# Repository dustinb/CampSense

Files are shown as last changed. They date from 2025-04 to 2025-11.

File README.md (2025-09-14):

# Camp Sense

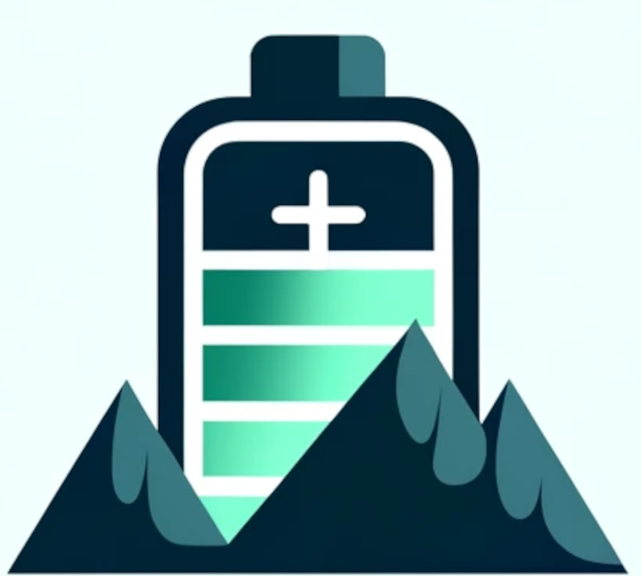
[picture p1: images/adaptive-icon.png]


**Battery energy monitoring and weather app with ESP32 hardware**

The Camp Sense app connects to the WattIsIt ESP32 hardware module via Bluetooth and displays battery energy usage and weather data.

## 🚀 Quick Start

- **📱 [Download App](https://apps.apple.com/us/app/camp-sense/id6741625671)** - Available on the App Store
- **🌐 [View Website](https://campsense.app)** - Full documentation and hardware details

## 📁 Repository Structure

- `App/` - React Native mobile app (Expo)
- `Arduino/` - ESP32 firmware sketch
- `v1.kicad_pro` - KiCad project

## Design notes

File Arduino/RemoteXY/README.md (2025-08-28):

## Remote XY

Before the Camp Sense app Remote XY was used for development. The sketch is in `Arduino/RemoteXY`.

The Remote XY is a free app is used to view data with bluetooh. This also has a setting for the shunt 50, 75, or 100 mV. The setting is persisted in eeprom (flash memory)

https://remotexy.com/en/editor/391325040dffc13fc4e74f019a2b24ee/

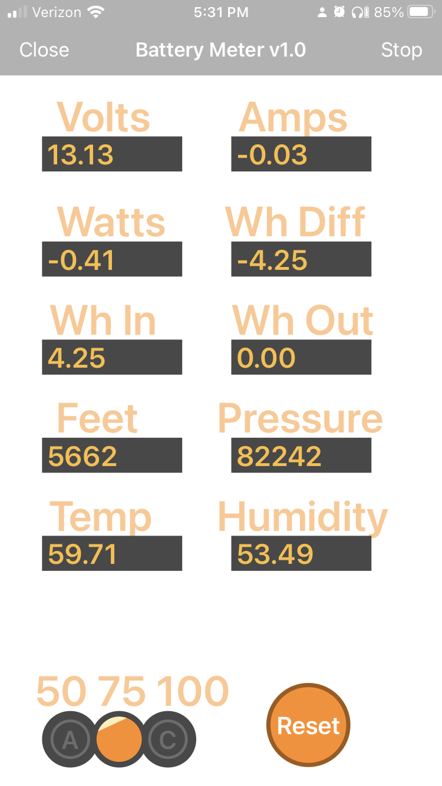
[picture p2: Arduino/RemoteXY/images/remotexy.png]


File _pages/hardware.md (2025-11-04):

---
layout: default
title: "Hardware - WattIsIt"
permalink: /hardware/
---

## WattIsIt Hardware

A battery watt meter using ADS1115 and a shunt to measure power usage. The Arduino sketch is located in `Arduino/WattIsIt`. Been using the DOIT ESP32 DEVKIT V1 board.

## Version 1.2

| KiCad Model | PCB |
| :---: | :---: |
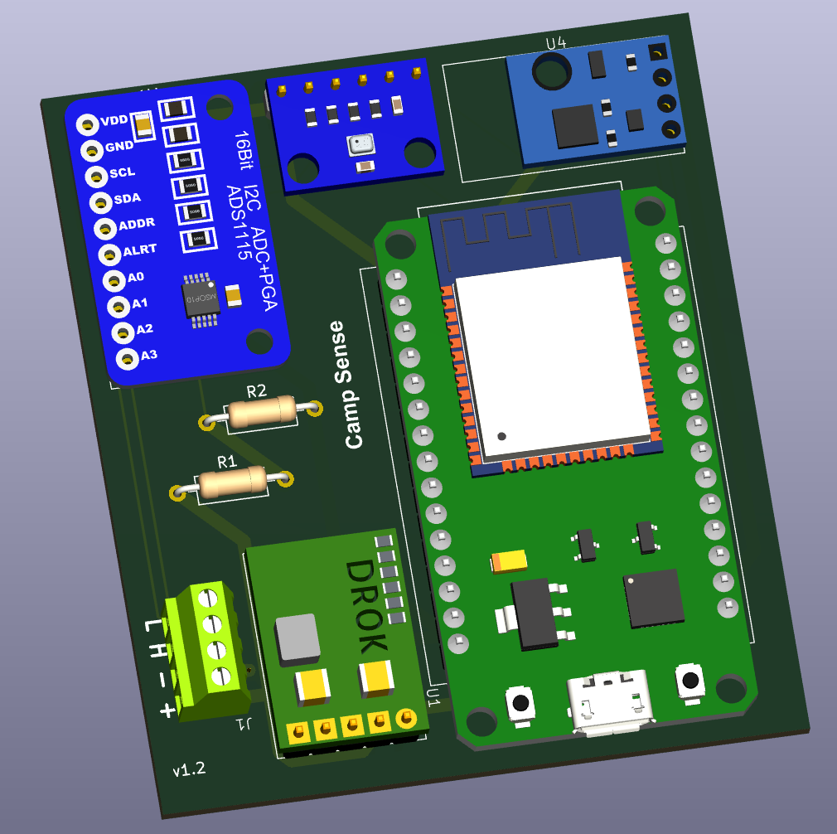
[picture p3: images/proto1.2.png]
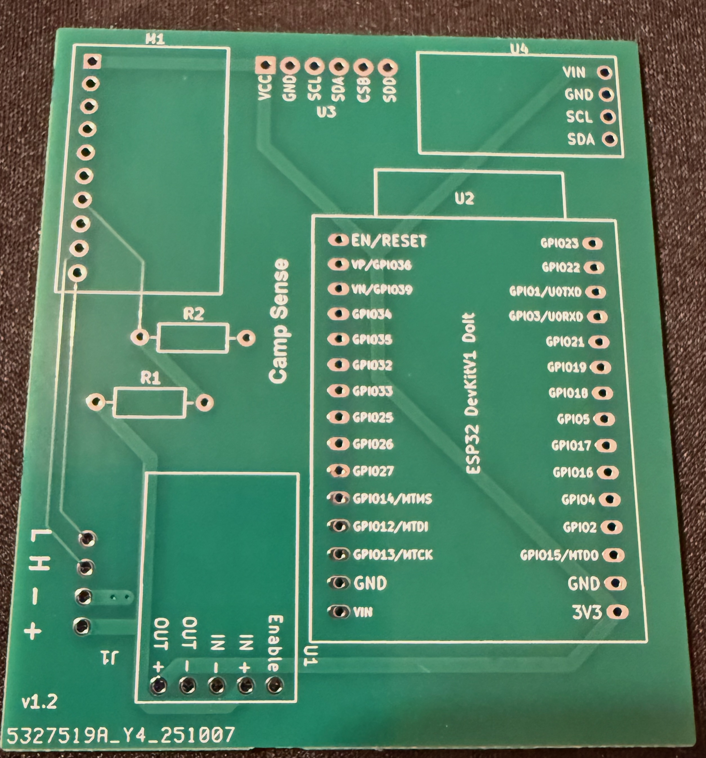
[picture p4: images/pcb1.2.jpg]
|  |  |

## Case & Battery Holder

Download all STLs for printing the hoder and case <a href="../images/camp_sense_stl.zip" >here</a>

| Hex | Oval |
| :---: | :---: |
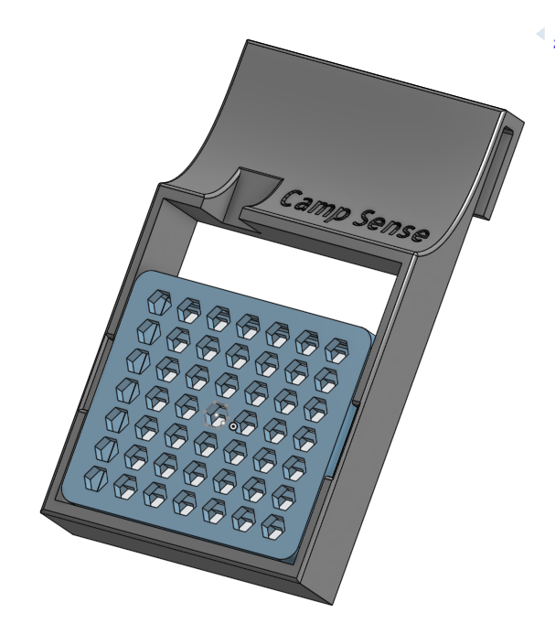
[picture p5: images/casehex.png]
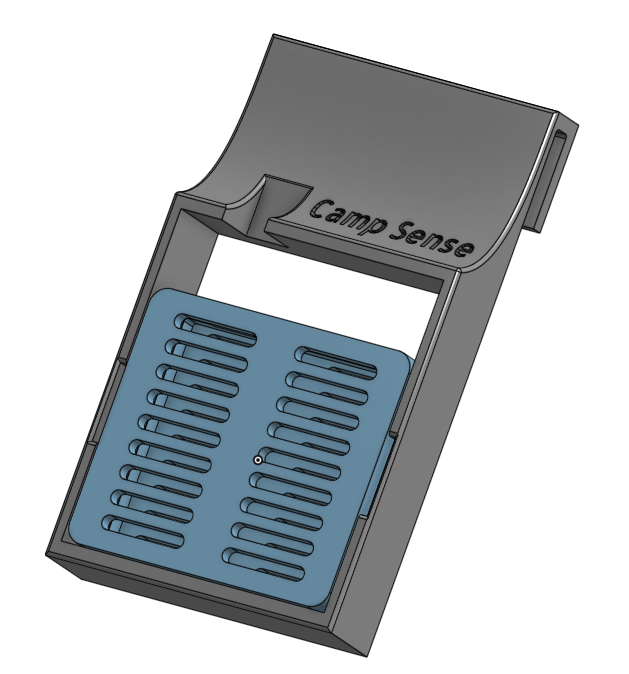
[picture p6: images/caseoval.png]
|   |  |

## Wiring Diagram

**+** Positive battery terminal

**-** Negative battery terminal

**L** Low side of current shunt resistor

**H** High side of current shunt resistor

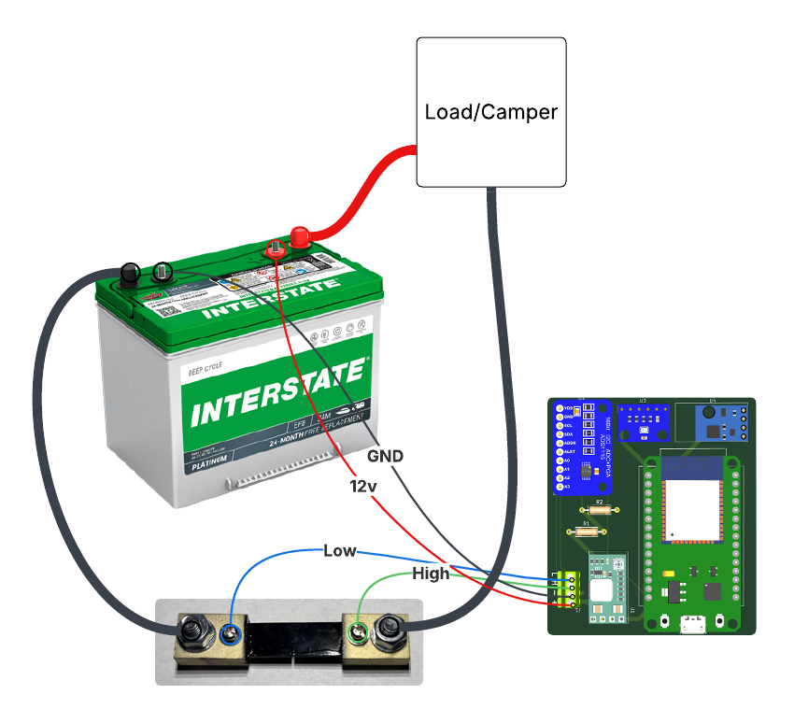
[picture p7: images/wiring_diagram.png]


## Bill of Materials

If using a BME280 on U3 can skip the AHT21 at U4.  The BME280 has tempurature, humidity and pressure/altitude.

| Item | Link |
| --- | --- |
| U2 ESP32 | [https://a.co/d/ff7WulK](https://a.co/d/ff7WulK) |
| M1 ADS1115 | [https://a.co/d/gfCO6jt](https://a.co/d/gfCO6jt) |
| U1 Voltage Reg | [https://a.co/d/2Gd8mMj](https://a.co/d/2Gd8mMj) |
| U4 AHT21 | [https://a.co/d/6xBWBLx](https://a.co/d/6xBWBLx) |
| U3 BMP280 | [https://a.co/d/1HV9oyw](https://a.co/d/1HV9oyw) |
| U3 BME280 | [https://a.co/d/eRQ7Lw4](https://a.co/d/eRQ7Lw4) |
| J1 Terminals | [https://a.co/d/8nVocXb](https://a.co/d/8nVocXb) |
| J1 JST Connector | [https://a.co/d/0xq4sMO](https://a.co/d/0xq4sMO) |
| Shunt | [https://a.co/d/2KoI4U9](https://a.co/d/2KoI4U9) |
| R1 36k Ohm | [https://a.co/d/88x0EcR](https://a.co/d/88x0EcR) |
| R2 10k Ohm | [https://a.co/d/3lXzVxy](https://a.co/d/3lXzVxy) |
| #10 Ring Terminal| [https://a.co/d/7aQ1Wun](https://a.co/d/7aQ1Wun) |
| M8 Ring Terminal | [https://a.co/d/6IeT5Sb](https://a.co/d/6IeT5Sb) |
| Conformal Coat | [https://a.co/d/5Z8R07R](https://a.co/d/5Z8R07R) |

## Arduino Code

The Arduino sketch for the WattIsIt module is available in the <a href="https://github.com/dustinb/CampSense/blob/master/Arduino/WattIsIt/WattIsIt.ino" target="_blank">Arduino/WattIsIt</a> directory. This code handles:

- Reading voltage and current measurements from the ADS1115 ADC
- Calculating power and energy usage
- Bluetooth communication with the mobile app
- Temperature and humidity sensing

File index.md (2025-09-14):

---
layout: default
title: "Camp Sense"
---

<div class="card">
  <p>The Camp Sense app connects to the WattIsIt ESP32 hardware module via Bluetooth and displays battery energy usage and weather data.</p>
  
  <p>The app shows current amps into (charging) or out (discharging). A total count shows how many watt hours went into and out of the battery. Long press the battery on screen to reset the Wh counters.</p>
  
  <p>Your shunt will have a voltage drop rating of 50mV, 75mV or 100mV. Long press the setting to set this for your shunt resistor.</p>
  
  <p>Access the weather screen by swiping left (and right on weather to return). The app is built with React Native using Expo.</p>
</div>

<div class="feature-grid">
  <div class="feature-card">
    <h3>🔋 Energy Monitoring</h3>
    <p>Real-time battery monitoring with current, voltage, and watt hour totals for charging and discharge.</p>
  </div>
  <div class="feature-card">
    <h3>🌤️ Weather Data</h3>
    <p>Weather information from sensors and astronomy data based on your location</p>
  </div>
  <div class="feature-card">
    <h3>📱 Mobile App</h3>
    <p>Cross-platform React Native app for iOS and Android (maybe)</p>
    <div class="app-store-badges">
  <a href="https://apps.apple.com/us/app/camp-sense/id6741625671" target="_blank" rel="noopener">
    
  </a>
</div>
  </div>
  <div class="feature-card">
    <h3>🔧 ESP32 Hardware</h3>
    <p>Custom PCB with ADS1115 ADC and Bluetooth connectivity. KiCad files provided, see <a href="/hardware">hardware</a></p>
  </div>
  <div class="feature-card">
    <h3>Open Source</h3>
    <p>Complete source code available on GitHub including React Native app, Arduino sketch, and KiCad PCB files</p>
    <a href="https://github.com/dustinb/CampSense" target="_blank" rel="noopener" class="github-link">
      <svg class="github-icon" viewBox="0 0 24 24" fill="currentColor">
        <path d="M12 0c-6.626 0-12 5.373-12 12 0 5.302 3.438 9.8 8.207 11.387.599.111.793-.261.793-.577v-2.234c-3.338.726-4.033-1.416-4.033-1.416-.546-1.387-1.333-1.756-1.333-1.756-1.089-.745.083-.729.083-.729 1.205.084 1.839 1.237 1.839 1.237 1.07 1.834 2.807 1.304 3.492.997.107-.775.418-1.305.762-1.604-2.665-.305-5.467-1.334-5.467-5.931 0-1.311.469-2.381 1.236-3.221-.124-.303-.535-1.524.117-3.176 0 0 1.008-.322 3.301 1.23.957-.266 1.983-.399 3.003-.404 1.02.005 2.047.138 3.006.404 2.291-1.552 3.297-1.23 3.297-1.23.653 1.653.242 2.874.118 3.176.77.84 1.235 1.911 1.235 3.221 0 4.609-2.807 5.624-5.479 5.921.43.372.823 1.102.823 2.222v3.293c0 .319.192.694.801.576 4.765-1.589 8.199-6.086 8.199-11.386 0-6.627-5.373-12-12-12z"/>
      </svg>
      View on GitHub
    </a>
  </div>
</div>

<div class="card">
  <h2>App Screenshots</h2>
  <table>
    <tr>
      <th>Energy Monitoring</th>
      <th>Weather Display</th>
    </tr>
    <tr>
      <td>Energy monitoring screen</td>
      <td>Weather display screen</td>
    </tr>
  </table>
</div>

<div class="quick-links">
  <h2>Quick Links</h2>
  <ul>
    <li><a href="/hardware/">🔧 Hardware Details</a><br><small>ESP32 WattIsIt module specifications and materials</small></li>
    <li><a href="/app/">📱 App Information</a><br><small>React Native app features and usage</small></li>
    <li><a href="/privacy/">🔒 Privacy Policy</a><br><small>Data usage and privacy information</small></li>
  </ul>
</div>

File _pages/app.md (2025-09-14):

---
layout: default
title: "App - Camp Sense Mobile"
permalink: /app/
---

# Camp Sense Mobile App

The Camp Sense app connects to the WattIsIt ESP32 hardware module via Bluetooth and displays battery energy usage and weather data.

## Features

### Energy Monitoring
- **Real-time Current Display**: Shows current amps into (charging) or out (discharging) the battery
- **Energy Tracking**: Total count of watt hours that went into and out of the battery
- **Reset Functionality**: Long press the battery on screen to reset the Wh counters
- **Shunt Configuration**: Long press the setting to configure your shunt resistor voltage drop rating (50mV, 75mV, or 100mV)

### Weather Information
- **Weather Screen**: Access by swiping left from the main screen
- **Return Navigation**: Swipe right on weather screen to return to energy view
- **Astronomy Data**: Optional sunrise, sunset, and other astronomy information based on location

## App Screenshots

| Energy | Weather |
| :---: | :---: |
|  |  |

## Technical Details

- **Framework**: React Native with Expo
- **Platform**: iOS and Android
- **Communication**: Bluetooth Low Energy (BLE) with ESP32
- **Location Services**: Optional for astronomy data
- **Data Source**: ipgeolocation.io Astronomy API

## Development

The app source code is located in the `App/` folder and includes:

- `src/Energy.js` - Energy monitoring components
- `src/Weather.js` - Weather display components  
- `src/useBLE.js` - Bluetooth communication hooks
- `src/useLocation.js` - Location services hooks
- `src/EnergyContext.js` - State management for energy data

## Download the App

<div class="app-store-badges">
  <a href="https://apps.apple.com/us/app/camp-sense/id6741625671" target="_blank" rel="noopener">
    
  </a>
</div>

<p><strong>Available now on the App Store!</strong> The app is free and works on iPhone, iPad, and Mac with Apple Silicon.</p>

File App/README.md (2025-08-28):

# iOS Installation

Install dependencies

`npm install`

Build for ios

`npx expo prebuild --platform ios`

Open `ios/CampSense.xcworkspace` in Xcode.  Edit the scheme and change the Build Configuration to Release.  This will install a release version not dependent on an expo dev server.

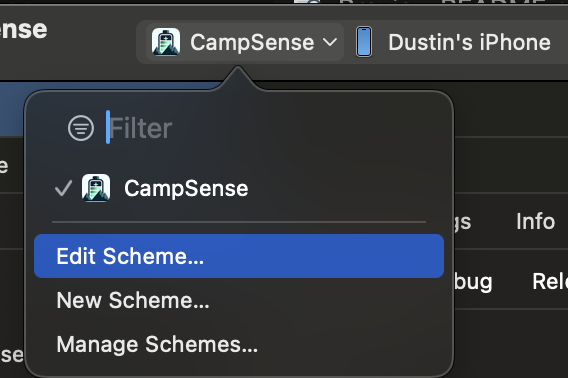
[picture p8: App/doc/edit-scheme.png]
Edit Scheme


 Select a team under Signing & Capabilities, click play to build the project to your iPhone.

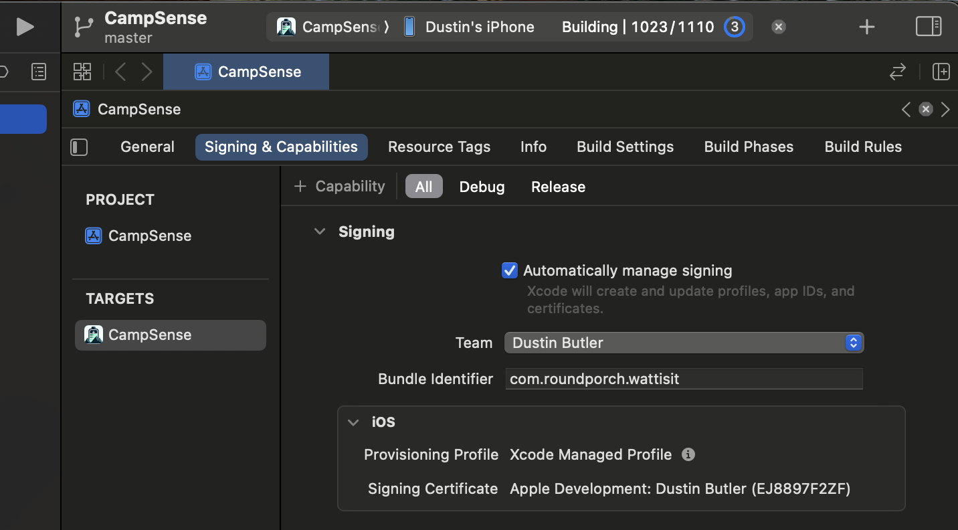
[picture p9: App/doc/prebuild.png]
Prebuild Screenshot


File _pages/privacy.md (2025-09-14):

---
layout: default
title: "Privacy Policy"
permalink: /privacy/
---

## Privacy Policy

This app is a basic energy monitor with optional astronomy features.

### Location Data

The app may request access to your location in order to retrieve sunrise, sunset, and other astronomy information. Location access is optional, and the app continues to function without it.

### How Data Is Used

Your location (if granted) is used only to request astronomy data from the ipgeolocation.io Astronomy API. This information is not stored, tracked, or shared by the app.

### No Data Collection

The app does not collect, store, or share personal information of any kind.

### Third-Party Services

The astronomy data is retrieved from ipgeolocation.io. Please review their privacy policy for details on how they handle requests.

### No Tracking

The app does not use analytics, advertising, or tracking tools.

### Data Security

- All data processing happens locally on your device
- No data is transmitted to our servers
- Bluetooth communication is only between your phone and the ESP32 device
- Location data (if used) is only sent to the astronomy API service

### Contact

If you have any questions about this privacy policy, please contact us through the project repository.

---

*Last updated: {{ site.time | date: "%B %d, %Y" }}*

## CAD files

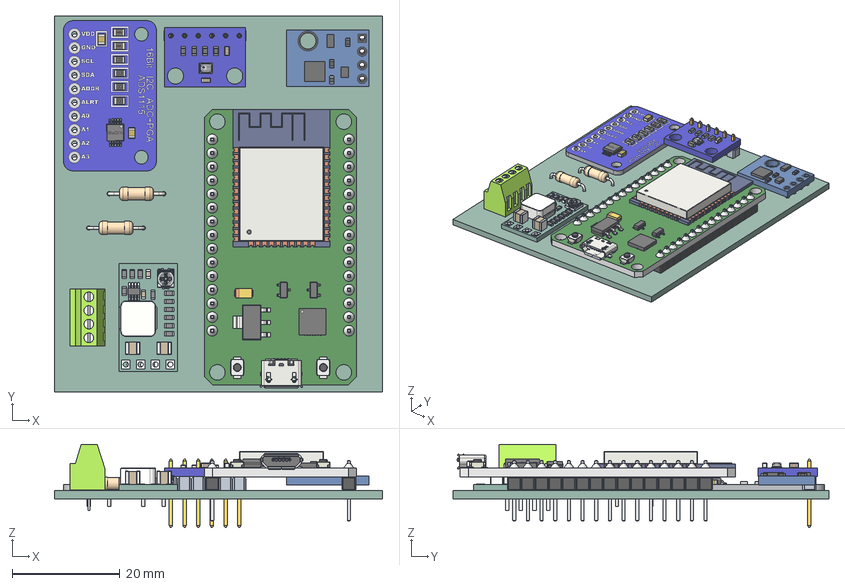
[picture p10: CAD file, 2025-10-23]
v1.step
61.0 x 69.8 x 15.4 mm
Печатная плата
ESP32-WROOM-32
USB_Micro-B_Molex_47346-0001
AMS-1117
cp2102
SOT_23-1
SOT_23-2
SW_SPST_B3U-1000P-1
SW_SPST_B3U-1000P-2
CP_EIA_3216_10_Kemet_I
PlasticBody
Housing
R_Axial_DIN0207_L6.3mm_D2.5mm_P10.16mm_Horizontal x 2
ADS1115
0805 Capacitor x 2
0805 Inductor x 2
0805 Resistor x 4
MSOP10
voltage controller
board
SMD RESISTOR, 104, DC-DC 4.5-28V to 0.8-20V Output 3A MP1584EN Step Down Buck Converter x 5
SMALL SMD CAPACITOR, DC-DC 4.5-28V to 0.8-20V Output 3A MP1584EN Step Down Buck Converter x 2
1818AW Inductor
large SMD resistor
trace pad x 7
SMD RESISTOR, 822, DC-DC 4.5-28V to 0.8-20V Output 3A MP1584EN Step Down Buck Converter x 6
POTENTIOMETER, DC-DC 4.5-28V to 0.8-20V Output 3A MP1584EN Step Down Buck Converter
large SMD resistor (1)
AHT20
v1_PCB

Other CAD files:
v1.stl

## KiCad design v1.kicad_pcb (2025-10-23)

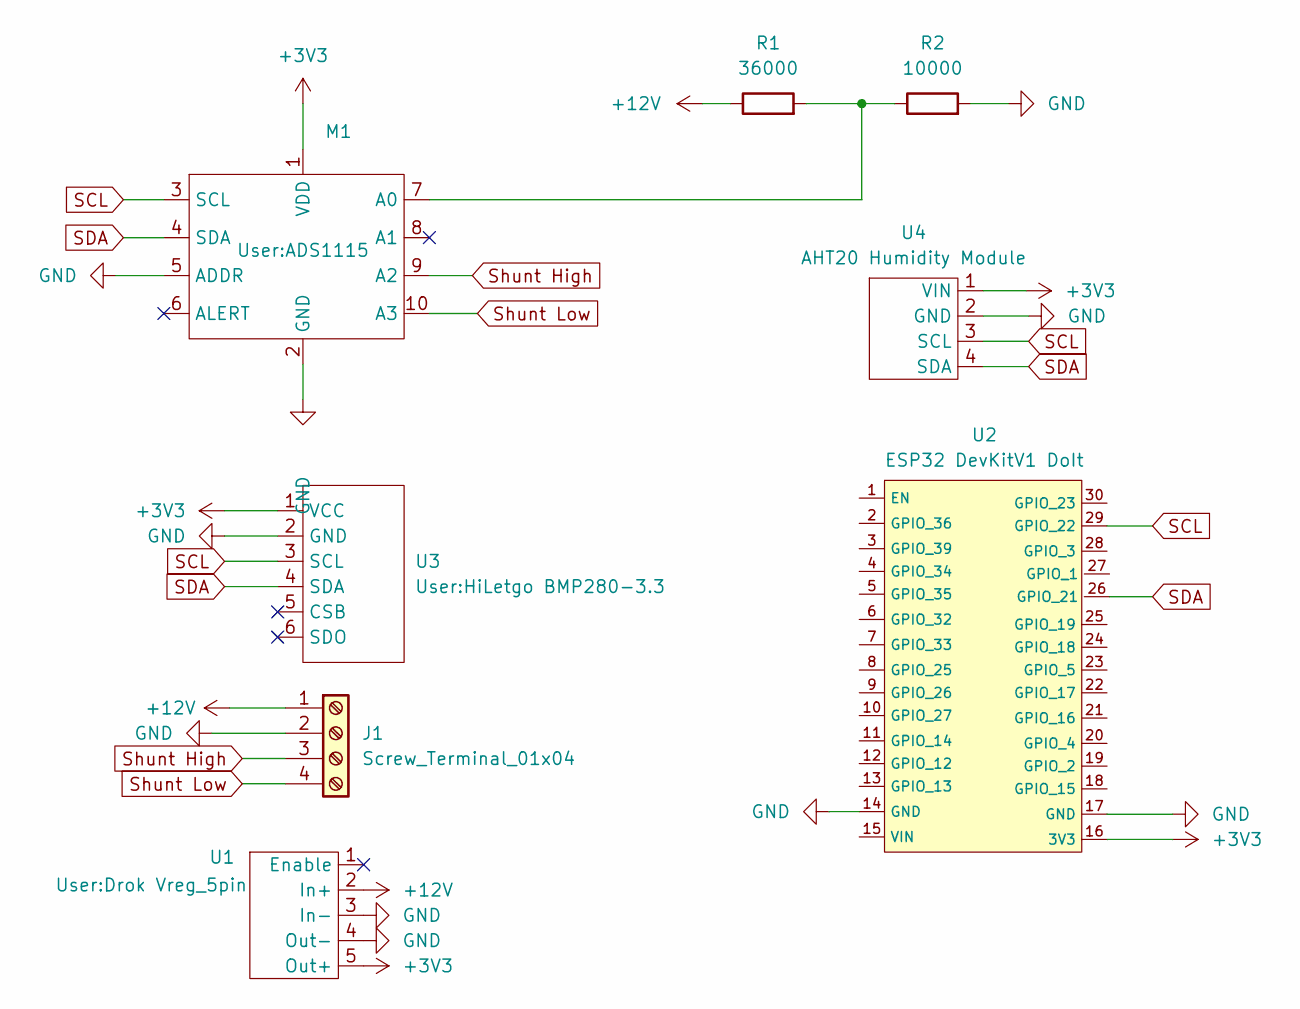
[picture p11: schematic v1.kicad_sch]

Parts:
J1: Screw_Terminal_01x04; Screw Terminal 2.54 x4
M1: ADS1115
R1: 36000; R_Axial_DIN0207_L6.3mm_D2.5mm_P10.16mm_Horizontal
R2: 10000; R_Axial_DIN0207_L6.3mm_D2.5mm_P10.16mm_Horizontal
U1: Drok Vreg_5pin
U2: ESP32 DevKitV1 DoIt
U3: HiLetgo BMP280-3.3
U4: AHT20 Humidity Module

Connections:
+3V3: M1.1 (VDD), U1.5 (Out+), U2.16 (3V3), U3.1 (VCC), U4.1 (VIN)
+12V: J1.1, R1.1, U1.2 (In+)
GND: J1.2, M1.2 (GND), M1.5 (ADDR), R2.2, U1.3 (In-), U1.4 (Out-), U2.14 (GND), U2.17 (GND), U3.2 (GND), U4.2 (GND)
unnamed: M1.7 (A0), R1.2, R2.1
SCL: M1.3 (SCL), U2.29 (GPIO_22), U3.3 (SCL), U4.3 (SCL)
SDA: M1.4 (SDA), U2.26 (GPIO_21), U3.4 (SDA), U4.4 (SDA)
Shunt High: J1.3, M1.9 (A2)
Shunt Low: J1.4, M1.10 (A3)

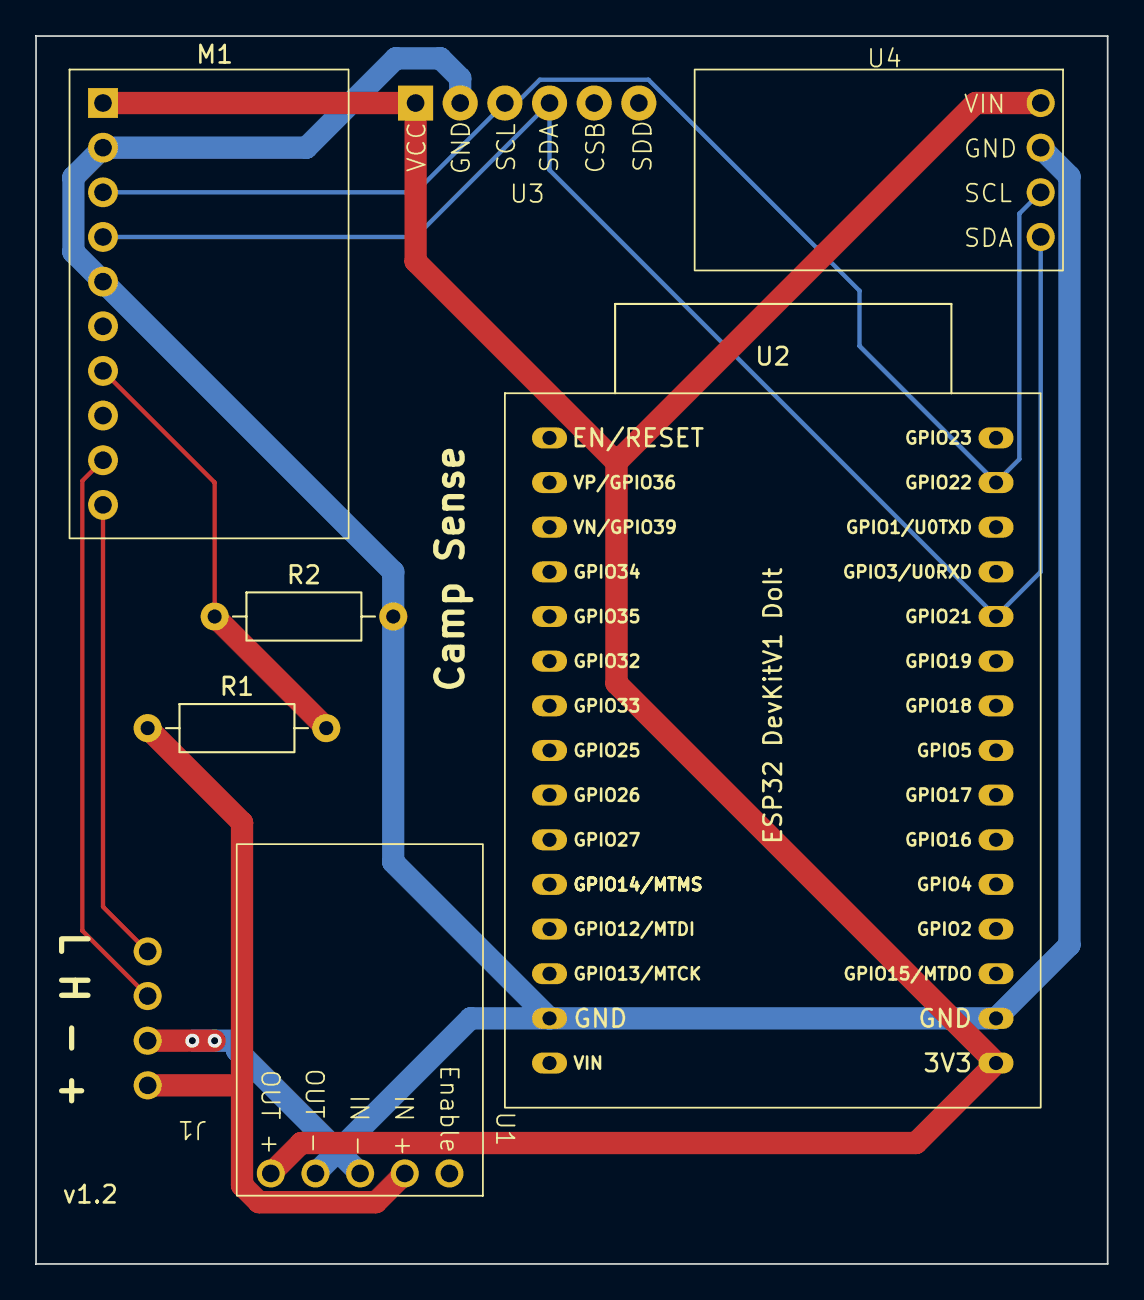
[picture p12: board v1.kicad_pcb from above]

Board: 2 copper layers, 61.0 x 69.8 mm, 8 parts (0 on the bottom side), 8 nets.

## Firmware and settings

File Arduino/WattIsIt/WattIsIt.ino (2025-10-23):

#include <Wire.h>
#include <EEPROM.h>
#include <BLEDevice.h>
#include <BLEServer.h>
#include <BLEUtils.h>
#include <BLE2902.h>

#define ADC // Enable ADS1115
// #define BMP280 // Enable BMP280
#define BME280 // Enable BME280
// #define AHT2x // Enable AHT2x

const int R1 = 36000;
const int R2 = 10000;

#define DEVICE_NAME "WattIsIt"

#define SERVICE_UUID "13030a97-68c2-4746-852a-3566bce33d89"
#define CHAR_UUID_WEATHER_DATA "eb19820c-c6cc-46a8-93a6-3645803d8e8f"
#define CHAR_UUID_ENERGY_DATA "1dc27998-20cd-4cf5-a5f3-3fe25f55c0f8"
#define CHAR_UUID_MV "6ebe8ad1-ab57-4f57-bf64-fd9ce197d9c4"

BLECharacteristic *pWeatherDataChar;
BLECharacteristic *pEnergyDataChar;
BLECharacteristic *pMvDataChar;

#ifdef ADC
#include "ADS1X15.h"
ADS1115 ADS(0x48);
#endif

#ifdef BMP280
#include "Adafruit_BMP280.h"
Adafruit_BMP280 bmp280;
#endif

#ifdef AHT2x
#include <AHT20.h>
AHT20 aht20;
#endif

#ifdef BME280
#include "Adafruit_BME280.h"
Adafruit_BME280 bme280;
#endif

float wattHoursCharge = 0;
float wattHoursDischarge = 0;
unsigned long lastADCRead = 0;
uint8_t mVSetting = 1;

class BaseBLEServerCallbacks : public BLEServerCallbacks
// Callback triggered when a client device connects or disconnects
{
  void onConnect(BLEServer *pServer)
  {
    Serial.println("Device connected");
  }

  void onDisconnect(BLEServer *pServer)
  {
    // Restart advertising
    Serial.println("Device disconnected");
    BLEAdvertising *pAdvertising = pServer->getAdvertising();
    if (pAdvertising)
    {
      pAdvertising->start();
    }
  }
};

// Got a new mV setting and/or reset request
class mvCallback : public BLECharacteristicCallbacks
{
  void onWrite(BLECharacteristic *pCharacteristic)
  {
    // std::string value = pCharacteristic->getValue();
    uint8_t* data = pCharacteristic->getData();
    size_t len = pCharacteristic->getLength();
    uint16_t newMV = (data[1] << 8) | data[0];
    uint16_t reset = (data[3] << 8) | data[2];
    if (newMV != mVSetting)
    {
      Serial.print("Setting mV to: ");
      Serial.println(newMV);
      mVSetting = newMV;
      EEPROM.write(0, mVSetting);
      EEPROM.commit();
    }
    if (reset > 0)
    {
      Serial.println("Resetting watt hours");
      wattHoursCharge = 0;
      wattHoursDischarge = 0;
    }
  }
};

void setup()
{
  Serial.begin(115200);
  Wire.begin();
  delay(1000);
  
  while(!Serial) {
    delay(10);
  }
  
#ifdef ADC
  ADS.begin();
#endif

#ifdef BMP280
  bmp280.begin(0x76, 0x58);
#endif

#ifdef AHT2x
  if (!aht20.begin()) {
    Serial.println("AHT20 sensor not found!");
  } else {
    Serial.println("AHT20 sensor initialized successfully");
  }
#endif

#ifdef BME280
  if (!bme280.begin(0x76)) {
    Serial.println("BME280 sensor not found!");
  } else {
    Serial.println("BME280 sensor initialized successfully");
  }
#endif

  EEPROM.begin(1); // Initialize EEPROM 1 bytes
  uint8_t eepromValue = EEPROM.read(0);
  if (eepromValue > 2)
  {
    // Default to 75mv if no value
    mVSetting = 1;
  }
  else
  {
    mVSetting = eepromValue;
  }

  lastADCRead = millis();

  // Create BLE server, and characteristics
  BLEDevice::init(DEVICE_NAME);

  BLEServer *pServer = BLEDevice::createServer();
  pServer->setCallbacks(new BaseBLEServerCallbacks());

  BLEService *pService = pServer->createService(SERVICE_UUID);

  pEnergyDataChar = pService->createCharacteristic(
      CHAR_UUID_ENERGY_DATA,
      BLECharacteristic::PROPERTY_READ | BLECharacteristic::PROPERTY_NOTIFY);
  pEnergyDataChar->addDescriptor(new BLE2902());

  pWeatherDataChar = pService->createCharacteristic(
      CHAR_UUID_WEATHER_DATA,
      BLECharacteristic::PROPERTY_READ | BLECharacteristic::PROPERTY_NOTIFY);
  pWeatherDataChar->addDescriptor(new BLE2902());

  pMvDataChar = pService->createCharacteristic(
      CHAR_UUID_MV,
      BLECharacteristic::PROPERTY_READ | BLECharacteristic::PROPERTY_WRITE);
  pMvDataChar->addDescriptor(new BLE2902());
  pMvDataChar->setCallbacks(new mvCallback());
  pMvDataChar->setValue(&mVSetting, mVSetting);

  // Start BLE server and advertising
  pService->start();
  BLEAdvertising *pAdvertising = BLEDevice::getAdvertising();
  pAdvertising->addServiceUUID(SERVICE_UUID);
  pAdvertising->setScanResponse(true);
  pAdvertising->setMinPreferred(0x06);
  pAdvertising->setMinPreferred(0x12);
  BLEDevice::startAdvertising();
  Serial.println("BLE device is ready to be connected");
}

void loop()
{

  struct WeatherData
  {
    float temperature;
    float humidity;
    float pressure;
    float altitude;
  };

  struct EnergyData
  {
    float volts;
    float amps;
    float wattHoursIn;
    float wattHoursOut;
  };

  WeatherData weather;
  EnergyData energyData;

  int notifyDelay = 500;
  float temp = 0;
  float tempCount = 0;

#ifdef BMP280
  temp += bmp280.readTemperature();
  tempCount++;
  weather.pressure = bmp280.readPressure();
  weather.altitude = bmp280.readAltitude() * 3.28084;

  Serial.print("Altitude: ");
  Serial.println(weather.altitude);
  Serial.print("Pressure: ");
  Serial.println(weather.pressure);
#endif

#ifdef AHT2x
  // Get the new temperature and humidity value
  temp += aht20.getTemperature();
  tempCount++;
  weather.humidity = aht20.getHumidity();

  Serial.print("Humidity: ");
  Serial.println(weather.humidity);

  // The AHT20 can respond with a reading every ~50ms. However, increased read time can cause the IC to heat around 1.0C above ambient.
  // The datasheet recommends reading every 2 seconds.
  delay(200);
#endif

#ifdef BME280
  temp += bme280.readTemperature();
  tempCount++;
  weather.pressure = bme280.readPressure();
  weather.altitude = bme280.readAltitude(1013.25) * 3.28084; // Sea level pressure in hPa
  weather.humidity = bme280.readHumidity();

  Serial.print("Humidity: ");
  Serial.println(weather.humidity);
  Serial.print("Pressure: ");
  Serial.println(weather.pressure);
  Serial.print("Altitude: ");
  Serial.println(weather.altitude);
#endif

#ifdef ADC
  ADS.setGain(1);
  int16_t adc = ADS.readADC(0);
  float f = ADS.toVoltage(1);
  float adcVolts = adc * f;

  // https://ohmslawcalculator.com/voltage-divider-calculator
  float vbat = ((R1 + R2) * adcVolts) / R2;
  energyData.volts = vbat;
  Serial.print("Voltage: ");
  Serial.println(vbat);

  // Differential shunt current
  // https://learnarduinonow.com/2015/05/11/reading-current-shunt-with-arduino.html
  int16_t results;
  ADS.setGain(16);
  unsigned long currentTime = millis();
  results = ADS.readADC_Differential_2_3();
  unsigned long delta = currentTime - lastADCRead;
  lastADCRead = millis();

  float amps = ((float)results * 256.0) / 32768.0; // 100mv shunt
  if (mVSetting == 1)
  {
    amps = amps * 1.333; // 75mv shunt
  }
  if (mVSetting == 0)
  {
    amps = amps * 2; // 50mv shunt
  }
  energyData.amps = amps;
  Serial.print("Amps: ");
  Serial.println(amps);

  float power = amps * vbat;
  float energy = (power * delta) / (3600.0 * 1000.0); // Convert milliseconds to hours

  if (energy < 0)
  {
    wattHoursCharge += energy * -1.0;
  }
  else
  {
    wattHoursDischarge += energy;
  }

  Serial.print("Watt Hours In: ");
  Serial.println(wattHoursCharge);
  energyData.wattHoursIn = wattHoursCharge;

  Serial.print("Watt Hours Out: ");
  Serial.println(wattHoursDischarge);
  energyData.wattHoursOut = wattHoursDischarge;
#endif

  // Average temp of all sensors
  if (tempCount > 0)
  {
    weather.temperature = temp / tempCount;
    Serial.print("Temp: ");
    Serial.println(weather.temperature);
  }

  // Pack the data into a byte array
  uint8_t weatherDataBytes[sizeof(WeatherData)];
  memcpy(weatherDataBytes, &weather, sizeof(WeatherData));
  pWeatherDataChar->setValue(weatherDataBytes, sizeof(WeatherData));
  pWeatherDataChar->notify(true);

  uint8_t energyDataBytes[sizeof(EnergyData)];
  memcpy(energyDataBytes, &energyData, sizeof(EnergyData));
  pEnergyDataChar->setValue(energyDataBytes, sizeof(EnergyData));
  pEnergyDataChar->notify(true);

  delay(1500);
}

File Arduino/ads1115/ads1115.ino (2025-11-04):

#include <Wire.h>

#include "ADS1X15.h"
ADS1115 ADS(0x48);

void setup() {
  // put your setup code here, to run once:
   Serial.begin(115200);

   Wire.begin();
   delay(1000);
   ADS.begin();
}

void loop() {
  // put your main code here, to run repeatedly:
  delay(1000);
  ADS.setGain(1);
  int16_t adc = ADS.readADC(0);
  float f = ADS.toVoltage(1);
  float adcVolts = adc * f;
  Serial.print("ADC: ");
  Serial.println(adcVolts);

  int R1 = 36000;
  int R2 = 10000;

  float vbat = ((R1 + R2) * adcVolts) / R2;
  Serial.print("Battery Voltage: ");
  Serial.println(vbat);
}

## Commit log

2025-08-28 Moved from platform.io to Arduino IDE
2025-09-04 Update BOM links
2025-09-18 Working on alternave voltage converter
    [v1.kicad_pcb, v1.kicad_sch, v1.step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]
2025-10-23 Version 1.2 pcb, 3.3 volt adc, updated step down
    [BatteryMeter-F_Silkscreen.gbr, BatteryMeter-NPTH.drl, BatteryMeter-PTH.drl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]
2025-11-04 Add case files
